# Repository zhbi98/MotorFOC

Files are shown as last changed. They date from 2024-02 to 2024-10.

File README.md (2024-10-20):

# 电机驱动套件

好久没更新个人项目进展了，这次自制了手掌一半大小的 FOC 矢量控制驱动器，用于驱动永磁同步电机（PMSM）。

这种电机不能像电风扇一样通电就转，需要使用三相交流电合成三维空间磁场来引导转子转动。

所以需要软件算法和硬件电路来将直流电逆变成交流电以及合成出矢量空间磁场。

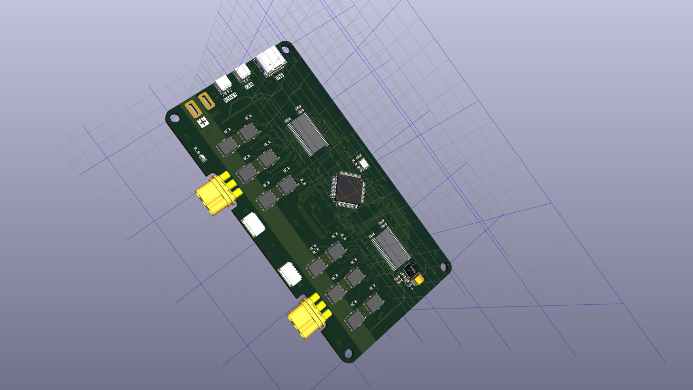
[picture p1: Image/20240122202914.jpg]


逆变电路采用了英飞凌的 DirectFET-MOS 管，最高电压 60V，单路最大驱动电流 100A，所以峰值输出功率高达 6KW。

板载了 RS485，CAN，USB，串口等总线，所以运行 Linux 系统的主控就可以和它通信了。

支持恒定扭矩，功率输出，做到低转速恒扭矩，并增加高精度磁编码器和闭环控制使得可以精确的控制电机转动角度。

还支持力反馈，就是说有了这个驱动器，电机转轴受到的阻力多大控制端可以感知到这个力，这对机器人的动作执行单元来说是必备条件。

配套的 AS5047 高精度 14 bit，高速 20K RPM 磁编码器模块，模块用于改装配套大疆精灵 3 拆机无刷电机 2312S，模块可以在淘宝搜索购买。

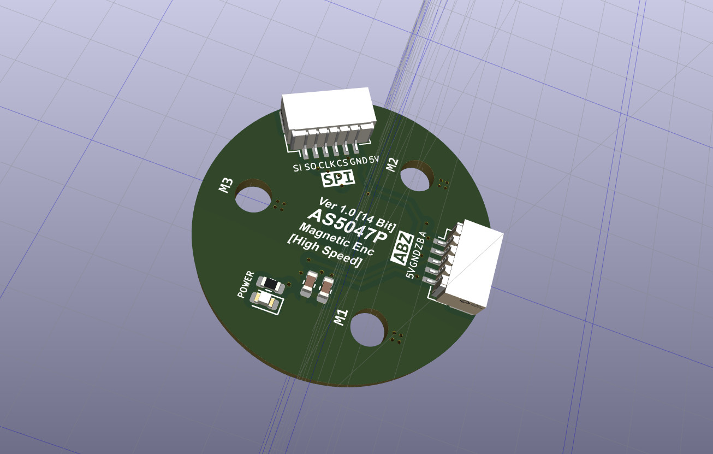
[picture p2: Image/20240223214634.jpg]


# 固件

我将 ODrive 的固件（驱动程序）适配到了 MotorKit 套件，简化了 ODrive 的文件组织方式，方便理解代码，并且将 ODrive 复杂的编译方式改成使用 CMake 进行构建，并且可以搭配 VSCode 进行图形化调试，这有利于理解 ODrive 的程序

基于 ODrive V5.6 改版的 MotorKit 固件，直接烧录到 MotorKit 就可以运行: https://github.com/zhbi98/ODrive

如果没有 VSCode 的嵌入式开发环境，可以看看这篇文章：https://blog.csdn.net/jf_52001760/article/details/126826393

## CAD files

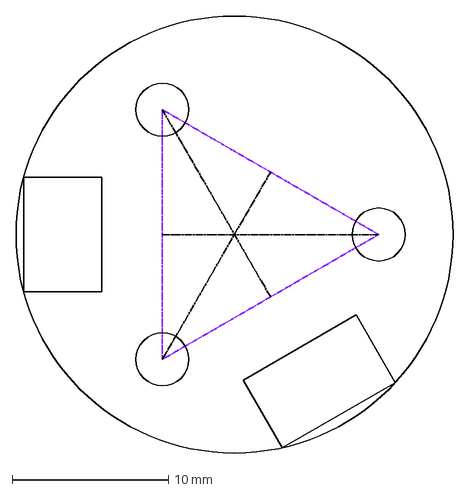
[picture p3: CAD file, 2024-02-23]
HardWare/AS5047P/AS5047P_TOP.dxf
28.0 x 28.0 mm

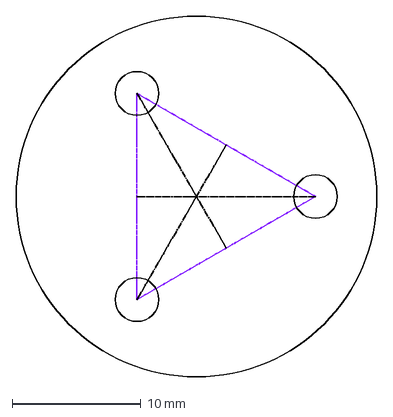
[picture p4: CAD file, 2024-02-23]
HardWare/AS5047P/AS5047P_EDG.dxf
28.0 x 28.0 mm

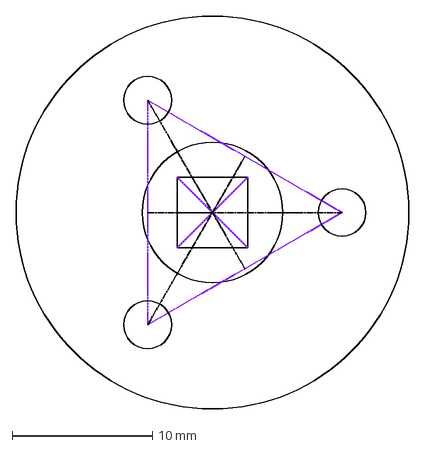
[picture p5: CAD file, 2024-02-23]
HardWare/AS5047P/AS5047P_BOM.dxf
28.0 x 28.0 mm

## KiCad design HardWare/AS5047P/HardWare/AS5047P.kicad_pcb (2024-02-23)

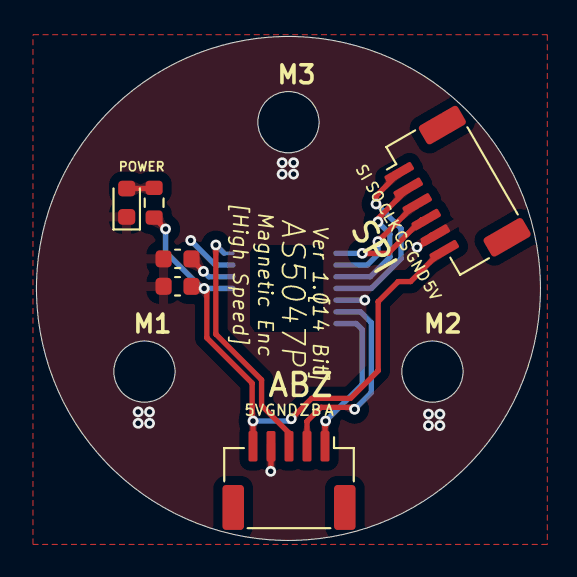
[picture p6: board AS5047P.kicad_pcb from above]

Board: 2 copper layers, 28.0 x 28.0 mm, 7 parts (1 on the bottom side), 11 nets.

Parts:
C1: 0.1uF; C_0603_1608Metric
C2: 1uF; C_0603_1608Metric
D1: Yellow LED; LED_0603_1608Metric
J1: CONN_1x5P; CONN-SMD_1x5P-P1.0-H_WAFER-SH1.0-5PWB
J2: CONN_1x5P; CONN-SMD_1x6P-P1.0-H_WAFER-SH1.0-6PWB
R1: 1K; R_0603_1608Metric
U1: AS5047D; TSSOP-14_4.4x5mm_P0.65mm

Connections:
+5V: C1.2, J1.5, J2.6, R1.1, U1.11 (VDD)
/A: J1.1, U1.7 (A)
/B: J1.2, U1.6 (B)
/CLK: J2.3, U1.2 (CLK)
/CS: J2.4, U1.1 (~CS)
/MISO: J2.2, U1.3 (MISO)
/MOSI: J2.1, U1.4 (MOSI)
/Z: J1.3, U1.14 (I/PWM)
GND: C1.1, C2.2, D1.1 (K), J1.4, J2.5, U1.5 (TST), U1.13 (GND)
unnamed: D1.2 (A), R1.2
unnamed: C2.1, U1.12 (VDD3V3)

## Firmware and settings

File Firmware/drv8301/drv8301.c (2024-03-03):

/**
 * @file drv8301.c
 *
 */

/*********************
 *      INCLUDES
 *********************/

#include "drv8301.h"
#include "time.h"
#include "spi.h"

/**********************
 *  STATIC VARIABLES
 **********************/

volatile uint16_t tx_buf = 0xFFFF, rx_buf = 0xFFFF;
volatile static uint8_t spi_tran_ret = 0xFF;
static md_drv8301_t * act_drv_p = NULL;

/**********************
 *  STATIC PROTOTYPES
 **********************/

static bool md_drv8301_spi_start(md_drv8301_t * drv8301_p, 
    const uint8_t * tx_buf, uint8_t * rx_buf, 
    size_t length);

/**********************
 *   GLOBAL FUNCTIONS
 **********************/

/**
 * Transmit and Receive an amount of data in non-blocking mode with DMA.
 * @param  tx_buf pointer to transmission data buffer
 * @param  rx_buf pointer to reception data buffer
 * @param  Size amount of data to be sent
 * @return HAL status.
 */
static bool md_drv8301_spi_start(md_drv8301_t * drv8301_p, 
    const uint8_t * tx_buf, uint8_t * rx_buf, 
    size_t length)
{
    HAL_DMA_StateTypeDef rdma = hspi3.hdmarx->State;
    HAL_DMA_StateTypeDef tdma = hspi3.hdmatx->State;
    HAL_StatusTypeDef status = HAL_ERROR;

    drv8301_p->pin_cs.setval(false);

    /*This can happen if the DMA or interrupt 
    priorities are not configured properly.*/
    if (rdma != HAL_DMA_STATE_READY || 
        tdma != HAL_DMA_STATE_READY) {
        status = HAL_BUSY;
    } else if (tx_buf && rx_buf) {
        status = HAL_SPI_TransmitReceive_DMA(
            &hspi3, (uint8_t *)tx_buf, 
            rx_buf, length);
    } else if (tx_buf) {
        status = HAL_SPI_Transmit_DMA(&hspi3, 
            (uint8_t *)tx_buf, 
            length);
    } else if (rx_buf) {
        status = HAL_SPI_Receive_DMA(&hspi3, 
            rx_buf, length);
    }

    if (status != HAL_OK) {
        drv8301_p->pin_cs.setval(true);
    }

    return (status != HAL_OK) ? 0 : 1;
}

/**
 * Transmit and Receive an amount of data in non-blocking mode with DMA.
 * @param  tx_buf pointer to transmission data buffer
 * @param  rx_buf pointer to reception data buffer
 * @param  Size amount of data to be sent
 * @return HAL status.
 */
void md_drv8301_spi_transfer_async(md_drv8301_t * drv8301_p, 
    const uint8_t * tx_buf, uint8_t * rx_buf, 
    size_t length)
{
    bool res = md_drv8301_spi_start(drv8301_p, 
        tx_buf, rx_buf, length);

    if (!res) spi_tran_ret = false;
    /*Note that the complete interrupt must be 
    sent by the SPI to set the state to true*/
    /*else spi_tran_ret = true;*/
}

/**
 * Transmit and Receive an amount of data in non-blocking mode with DMA.
 * @param  tx_buf pointer to transmission data buffer
 * @param  rx_buf pointer to reception data buffer
 * @param  Size amount of data to be sent
 * @return HAL status.
 */
bool md_drv8301_spi_transfer(md_drv8301_t * drv8301_p, 
    const uint8_t* tx_buf, uint8_t* rx_buf, 
    size_t length, uint32_t timeout_ms)
{
    spi_tran_ret = 0xFF;
    act_drv_p = drv8301_p;

    md_drv8301_spi_transfer_async(drv8301_p, 
        tx_buf, rx_buf, length);

    /*Wait for the conversion to complete*/
    while (spi_tran_ret == 0xFF) {sleep_us(1);}

    return spi_tran_ret;
}

/**
 * SPI Transmit and Receive completed callback.
 * act_drv_p pointer to a The currently active drive object.
 */
void md_drv8301_spi_transfer_end()
{
    /*The data is sent, cancel the DRV8301 chip selection*/
    act_drv_p->pin_cs.setval(true);
    /*The data is sent and the state is set to true*/
    spi_tran_ret = true;
}

/**
 * Based on the actual combination of configuration parameters, 
 * a frame of configuration data is constructed and stored, 
 * where the data is not immediately updated to the device. 
 * If the gate driver was in ready state and the new 
 * configuration is different from the old one then 
 * the gate driver will exit ready state.
 * @param drv8301_p pointer to DRV8301 that are currently 
 * in the configuration phase.
 * @param requested_gain The value of the gain requested.
 * @param actual_gain Match to a close gain value.
 * @return Configuration result.
 */
bool md_drv8301_register_config(md_drv8301_t * drv8301_p, 
    float requested_gain, float * actual_gain)
{
    /*Calculate gain setting: Snap down to have equal or 
      larger range as requested or largest possible 
      range otherwise*/

    const float kgain_all[4] = {10.0f, 20.0f, 40.0f, 80.0f};
    uint16_t kgain_idx = 3;

    /**
     * For reference:
     * 20V/V on 500uOhm gives a range of +/- 150A
     * 40V/V on 500uOhm gives a range of +/- 75A
     * 20V/V on 666uOhm gives a range of +/- 110A
     * 40V/V on 666uOhm gives a range of +/- 55A
     */

    while (kgain_idx && (kgain_all[kgain_idx] > requested_gain)) {kgain_idx--;}
    if (actual_gain != NULL) *actual_gain = kgain_all[kgain_idx];

    md_regctl_t _regctl = {0};

    _regctl.reg1data = 
        /**< Overcurrent set to approximately 
        150A at 100 degC, this may need tweaking.*/
        (21 << 6) 
        /**< OCP_MODE: latch shut down*/
        | (0b01 << 4)
        /**< Driver mode 6x PWM mode*/  
        | (0b0 << 3)
        /**< Don't reset latched faults*/ 
        | (0b0 << 2)  
        /**< Gate-drive peak current: 1.7A*/ 
        | (0b00 << 0);

    _regctl.reg2data =
        /**< OC_TOFF: cycle by cycle*/
        (0b0 << 6)
        /**< Calibration off (normal operation)*/
        | (0b00 << 4)
        /**< Select shunt current amp gain*/
        | (kgain_idx << 2)
        /**< report both over temperature 
        and over current on nOCTW pin*/
        | (0b00 << 0);

    md_regctl_t regctl = drv8301_p->regctl;

    /*Check if register values have changed*/
    bool regs_equal = (
        regctl.reg1data == _regctl.reg1data
    ) && (
        regctl.reg2data == _regctl.reg2data
    );

    /*The new configuration is different 
    from the original configuration and requires 
    the configuration value to be updated*/
    if (!regs_equal) {
        drv8301_p->regctl = _regctl;
        drv8301_p->init_state = \
            STATE_UNINITED;
        drv8301_p->pin_en.setval(false);
    }

    return true;
}
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

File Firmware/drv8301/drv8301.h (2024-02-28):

/**
 * @file drv8301.h
 *
 */

#ifndef __DRV8301_H__
#define __DRV8301_H__

/*********************
 *      INCLUDES
 *********************/

#include <stdbool.h>
#include <stdint.h>
#include <stdlib.h>

/*********************
 *      DEFINES
 *********************/

/**********************
 *      TYPEDEFS
 **********************/

/**
 * Contains fault information for status registers 1 and status 2.
 * where FAULT_GVDD_OV is the failure of status register 2.
 */
enum {
    FAULT_NOFAULT  = (0 <<  0), /**< No fault*/
    FAULT_FETLC_OC = (1 <<  0), /**< FET low side, phase C over current fault*/
    FAULT_FETHC_OC = (1 <<  1), /**< FET high side, phase C over current fault*/
    FAULT_FETLB_OC = (1 <<  2), /**< FET low side, phase B over current fault*/
    FAULT_FETHB_OC = (1 <<  3), /**< FET high side, phase B over current fault*/
    FAULT_FETLA_OC = (1 <<  4), /**< FET low side, phase A over current fault*/
    FAULT_FETHA_OC = (1 <<  5), /**< FET high side, phase A over current fault*/
    FAULT_OTW      = (1 <<  6), /**< Over temperature warning fault*/
    FAULT_OTSD     = (1 <<  7), /**< Over temperature shut down fault*/
    FAULT_PVDD_UV  = (1 <<  8), /**< Power supply Vdd under voltage fault*/
    FAULT_GVDD_UV  = (1 <<  9), /**< DRV8301 Vdd under voltage fault*/
    FAULT_FAULT    = (1 << 10), /**< DRV8301 Vdd over voltage fault*/
    FAULT_GVDD_OV  = (1 << 23)  /**< DRV8301 Vdd over voltage fault*/
};

/*The fault type of the MOS driver IC*/
typedef uint16_t md_fault_t;

/**
 * DRV8301 register address, DRV8301 There are 
 * four registers, two of which are control registers and 
 * two of which are status registers.
 */
enum {
    ADDR_REG_STA1 = 0x00 << 11, /**< DRV8301 Status Register 1*/
    ADDR_REG_STA2 = 0x01 << 11, /**< DRV8301 Status Register 2*/
    ADDR_REG_CTL1 = 0x02 << 11, /**< DRV8301 Control Register 1*/
    ADDR_REG_CTL2 = 0x03 << 11  /**< DRV8301 Control Register 2*/
};

typedef uint16_t md_addr_t;

/**
 * DRV8301 Register configuration status
 * and is available via a API.
 */
enum {
    STATE_UNINITED = 0,
    STATE_CHECKS,
    STATE_READY,
};

typedef uint8_t md_state_t;

/**
 * for the drv8301's SPI R/W modes.
 */
enum {
    READ  = 1 << 15, /**< Read Mode*/
    WRITE = 0 << 15  /**< Write Mode*/
};

typedef uint16_t md_RW_t;

/*Dev Select the I/O operation portal*/
typedef void (*_setval_t)(bool val);
/*Dev Select the I/O operation portal*/
typedef bool (*_readval_t)();

/**
 * Multiple DRV8301 involve a common pin definition that 
 * makes it easy to drive the pins of a given object.
 */
typedef struct {
    _setval_t setval;
    _readval_t readval;
} md_pin_t;

/**
 * Used to store the configuration values 
 * of the DRV8301 control registers.
 */
typedef struct {
    uint16_t reg1data;
    uint16_t reg2data;
} md_regctl_t;

/**
 * Object-oriented design, construct a MOSFET-Driven 
 * device descriptor to store device parameters
 */
typedef struct {
    uint8_t init_state;
    md_regctl_t regctl;
    md_pin_t pin_nfalt; /**< Multiple DRV8301common pin*/
    md_pin_t pin_cs;    /**< Multiple DRV8301 common pin*/
    md_pin_t pin_en;    /**< Multiple DRV8301 common pin*/
} md_drv8301_t;

/**********************
 * GLOBAL PROTOTYPES
 **********************/

/**
 * Transmit and Receive an amount of data in non-blocking mode with DMA.
 * @param  tx_buf pointer to transmission data buffer
 * @param  rx_buf pointer to reception data buffer
 * @param  Size amount of data to be sent
 * @return HAL status.
 */
void md_drv8301_spi_transfer_async(md_drv8301_t * drv8301_p, 
    const uint8_t * tx_buf, uint8_t * rx_buf, 
    size_t length);

/**
 * Transmit and Receive an amount of data in non-blocking mode with DMA.
 * @param  tx_buf pointer to transmission data buffer
 * @param  rx_buf pointer to reception data buffer
 * @param  Size amount of data to be sent
 * @return HAL status.
 */
bool md_drv8301_spi_transfer(md_drv8301_t * drv8301_p, 
    const uint8_t* tx_buf, uint8_t* rx_buf, 
    size_t length, uint32_t timeout_ms);

/**
 * SPI Transmit and Receive completed callback.
 * act_drv_p pointer to a The currently active drive object.
 */
void md_drv8301_spi_transfer_end();

bool md_drv8301_register_config(md_drv8301_t * drv8301_p, 
    float requested_gain, float * actual_gain);

/**
 * Apply the changed configuration parameters to the actual DRV8301 device.
 * @param drv8301_p pointer to DRV8301 that are currently 
 * in the configuration phase.
 * @return Configuration result.
 */
bool md_drv8301_register_init(md_drv8301_t * drv8301_p);

/**
 * Writes data to a DRV8301 register. There is no check if the write succeeded.
 * @param drv8301_p pointer to DRV8301 that are currently 
 * in the configuration phase.
 * @return Configuration result.
 */
bool md_drv8301_write_reg(md_drv8301_t * drv8301_p, 
    uint16_t reg_addr, uint16_t data);

/**
 * Reads data from a DRV8301 register.
 * @param drv8301_p pointer to DRV8301 that are currently 
 * in the configuration phase.
 * @return Configuration result.
 */
bool md_drv8301_read_reg(md_drv8301_t * drv8301_p, 
    uint16_t reg_addr, uint16_t * data_p);

/**
 * Assemble data fields, build data.
 * @param drv8301_p pointer to DRV8301 that are currently 
 * in the configuration phase.
 * @return Build the field.
 */
uint16_t build_spi_data(uint16_t _mode, uint16_t reg_addr, 
    uint16_t data);

/**
 * Transmit and Receive an amount of data in non-blocking mode with DMA.
 * @param drv8301_p pointer to DRV8301 that are currently 
 * in the configuration phase.
 * @return Failure field.
 */
md_fault_t md_drv8301_get_error(md_drv8301_t * drv8301_p);

/**
 * Monitors the nFAULT pin. This must be run at an interval of <8ms from the moment the init()
 * functions starts to run, otherwise it's possible that a temporary power
 * loss is missed, leading to unwanted register values.
 * In case of power loss the nFAULT pin can be low for as little as 8ms.
 * @param drv8301_p pointer to DRV8301 that are currently 
 * in the configuration phase.
 */
void md_drv8301_checks(md_drv8301_t * drv8301_p);

/**
 * Returns true if and only if the DRV8301 chip is in an initialized
 * state and ready to do switching and current sensor opamp operation.
 * @param drv8301_p pointer to DRV8301 that are currently 
 * in the configuration phase.
 * @return is ready.
 */
bool md_drv8301_ready(md_drv8301_t * drv8301_p);

#endif /*__DRV8301_H__*/

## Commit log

2024-01-26 CMake脚本配置,添加文件
2024-01-31 新增工程配置，硬件验证
    [MotorKit-B_Cu.gbr, MotorKit-B_Mask.gbr, MotorKit-B_Paste.gbr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]
2024-01-31 硬件原理图增加标注说明
2024-02-01 重构Modbus解析框架
2024-02-03 添加硬件总线驱动
2024-02-04 添加设计资料，修复Modbus框架BUG
2024-02-05 数据同步和绑定方式
2024-02-23 添加AS5047P无刷电机硬件模块设计
    [AS5047P.kicad_pcb, AS5047P.kicad_sch, AS5047P_BOM.dxf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]
2024-02-28 DRV8301驱动更新
2024-03-03 设备驱动调试
2024-05-14 添加 Modbus 使用示例
